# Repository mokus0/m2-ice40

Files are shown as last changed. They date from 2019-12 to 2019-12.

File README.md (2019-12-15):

This is a work in progress.  The end goal is to develop a m.2 3042 B-key (USB) board to install into my System76 Galago Pro laptop's internal 3G/LTE module socket, to provide a debugging and development tool for work on the system's Embedded Controller.

In particular, this board will include:
* a Lattice Semiconductor ICE40 FPGA with programming and USB interface (based on FTDI FT2232H high-speed USB interface as used in the "iCEstick" dev board, but upgraded from HX1K to HX4K FPGA)
* a MAX6621 I2C-to-PECI translator, to experiment with
* configurable power source; run from either 3.3v provided to the m.2 module or a wire to steal power from somewhere else in the system
* pads to connect FPGA as desired to various nets on the system board for monitoring and logging
* TODO (maybe in a second rev, and space permitting): a small microcontroller, perhaps STM32L4R5

Intended uses include:
* Investigating the traffic on the LPC bus, to develop sufficient understanding to be able to implement the bus in a new non-ITE processor, and later to monitor that processor's usage of the LPC bus for correctness
* Ability to log and monitor behavior of EC long-term

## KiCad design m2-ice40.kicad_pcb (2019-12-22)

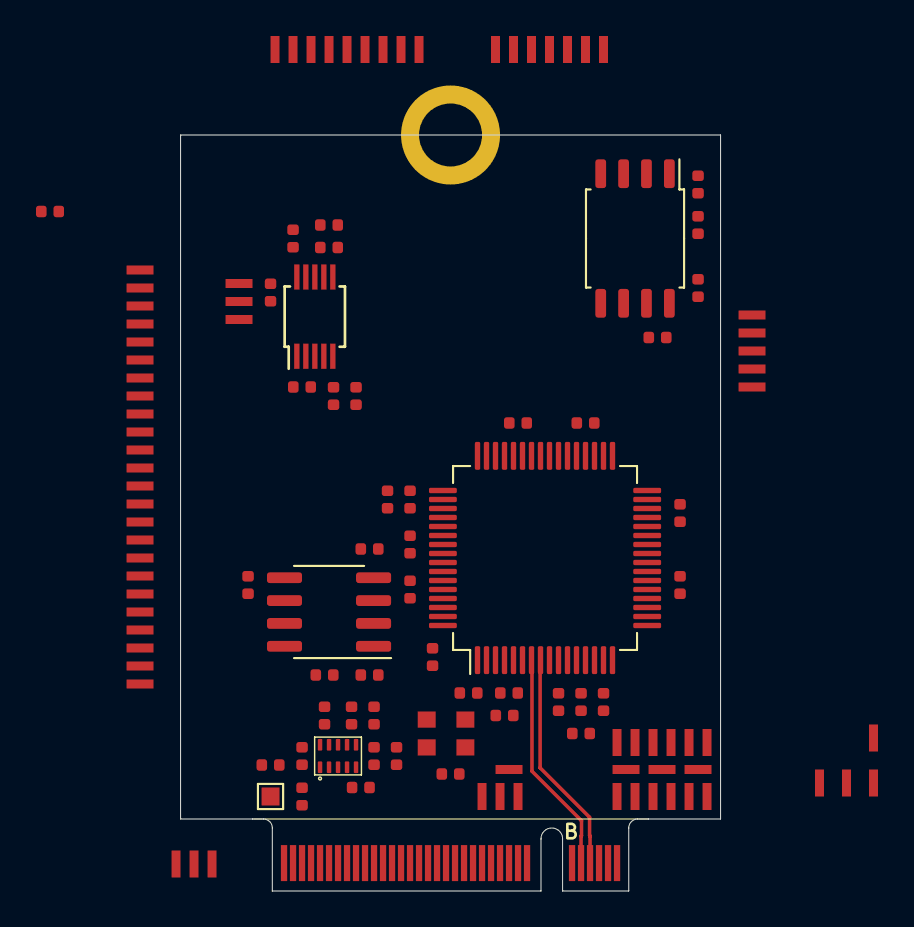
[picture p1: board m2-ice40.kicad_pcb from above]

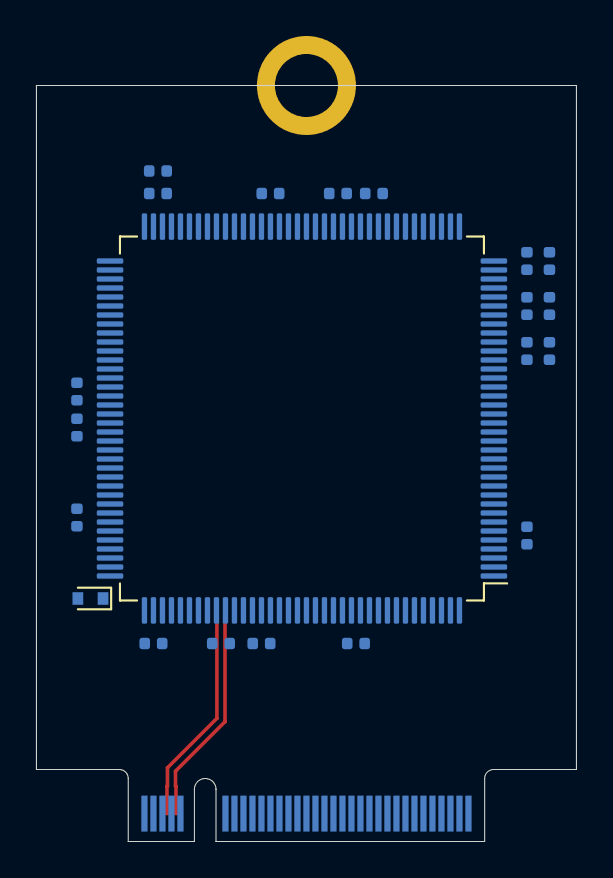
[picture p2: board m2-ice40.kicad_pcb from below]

Board: 4 copper layers, 30.0 x 42.0 mm, 146 parts (21 on the bottom side), 123 nets.

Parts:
C201, C202, C204, C207, C208, C209, C210, C211, C212, C213, C214, C215, C301, C302, C303, C304, C305, C306, C307, C308, C401, C402, C403, C406, C407, C408, C409, C701, C702: 0.1u; C_0402_1005Metric
C203, C404, C410, C503, C504: 10u; C_0402_1005Metric
C205, C206, C501: 4.7u; C_0402_1005Metric
C405: 0.01u; C_0402_1005Metric
C502: 120p; C_0402_1005Metric
D401: CDBU0520; D_SOD-523
J601: m.2_socket2_module; m2-padKeyB
J602: M.2-GND-MOUNTING; m.2_mechanical_ground_pad
R201, R203, R206, R401, R402, R403, R404, R701: 10k; R_0402_1005Metric
R202, R501, R502, R702: 0; R_0402_1005Metric
R204, R703, R704, R705: 2.2k; R_0402_1005Metric
R205: 12k 1%; R_0402_1005Metric
R207: 12k; R_0402_1005Metric
R405: 100; R_0402_1005Metric
R503, R504, R505: 100k; R_0402_1005Metric
TP101: PECI_VREF; TestPoint_Pad_0.5x1.5mm
TP102: PECI; TestPoint_Pad_0.5x1.5mm
TP103: PECI_GND; TestPoint_Pad_0.5x1.5mm
TP501: 3.3V_EXT; TestPoint_Pad_1.0x1.0mm
TP701, TP702, TP703, TP704, TP705, TP706, TP707, TP708, TP709, TP710, TP711, TP712, TP713, TP714, TP715, TP716, TP717, TP718, TP719, TP720, TP721, TP722, TP723, TP724, TP725, TP726, TP727, TP728, TP729, TP730, TP731, TP732, TP733, TP734, TP735, TP736, TP737, TP738, TP739, TP740, TP741, TP742, TP743, TP744, TP745, TP746, TP747, TP748, TP749, TP750, TP751, TP752, TP753, TP754, TP755, TP756, TP757, TP758, TP759, TP760, TP761, TP762, TP763, TP764, TP765, TP766, TP767, TP768, TP769, TP770, TP771: TestPoint; TestPoint_Pad_0.5x1.5mm
U201: 93LC56C-I/SN; SOIC-8_3.9x4.9mm_P1.27mm
U202: FT2232H; LQFP-64_10x10mm_P0.5mm
U301: ICE40HX1K-TQ144; TQFP-144_20x20mm_P0.5mm
U401: W25Q80DVSNIG; SOIC-8_5.23x5.23mm_P1.27mm
U501: TPSM82821; SIL0010D
U701: MAX6621; MSOP-10_3x3mm_P0.5mm
X201: DSC6001JI2A-012.0000; Oscillator_SMD_EuroQuartz_XO32-4Pin_3.2x2.5mm

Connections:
/FPGA/1.8v_OD_SIM_DETECT: J601.66, U301.139
/FPGA/ACBUS0: U202.26, U301.97
/FPGA/ACBUS1: U202.27, U301.96
/FPGA/ACBUS2: U202.28, U301.95
/FPGA/ACBUS3: U202.29, U301.91
/FPGA/ACBUS4: U202.30, U301.90
/FPGA/ACBUS5: U202.32, U301.88
/FPGA/ACBUS6: U202.33, U301.87
/FPGA/ACBUS7: U202.34, U301.81
/FPGA/ADBUS7: U202.24, U301.98
/FPGA/DISABLE#: J601.8, U301.121
/FPGA/FTDI_CTS: U202.19, U301.104
/FPGA/FTDI_DCD: U202.23, U301.99
/FPGA/FTDI_DSR: U202.22, U301.101
/FPGA/FTDI_DTR: U202.21, U301.102
/FPGA/FTDI_RTS: U202.18, U301.105
/FPGA/FTDI_RX__ICE_TX: U202.17, U301.106
/FPGA/FTDI_TX__ICE_RX: U202.16, U301.107
/FPGA/ICE_CLK: R202.1, U301.129
/FPGA/PECI_RESET#: R701.1, U301.39, U701.8
/FPGA/PECI_SCL: R705.2, U301.42, U701.5
/FPGA/PECI_SDA: R704.2, U301.41, U701.4
/FPGA/POWER_OFF#: J601.6, U301.120
/FPGA/RESET#: J601.67, U301.141
/FPGA/UIM_CLK: J601.32, U301.136
/FPGA/UIM_DATA: J601.34, U301.137
/FPGA/UIM_PWR: J601.36, U301.138
/FPGA/UIM_RESET: J601.30, U301.135
/fpga power and config/1.2V: C405.1, C406.1, C407.1, C408.1, C409.1, C410.1, C502.1, C503.1, C504.1, R405.1, R503.1, R504.1, U301.27, U301.51, U301.92, U301.111, U501.5, U501.6, U501.7
/fpga power and config/3.3V: C201.1, C202.1, C205.1, C206.1, C207.1, C208.1, C209.1, C211.1, C213.1, C215.1, C301.1, C302.1, C303.1, C304.1, C305.1, C306.1, C307.1, C308.1, C401.1, C402.1, C501.1, C701.1, D401.2, R201.1, R203.1, R206.1, R207.1, R401.1, R402.2, R403.2, R404.1, R501.1, R502.1, R701.2, R703.1, R704.1, R705.1, U201.6, U201.8, U202.4, U202.9, U202.20, U202.31, U202.42, U202.50, U202.56, U301.6, U301.30, U301.46, U301.57, U301.72, U301.89, U301.100, U301.123, U301.133, U401.8, U501.1, U501.2, U501.3, U701.6, X201.1, X201.4
/fpga power and config/CDONE: U202.45, U301.65
/fpga power and config/CRESET: R404.2, U202.46, U301.66
/fpga power and config/GNDPLL: C403.2, C404.2, U301.35
/fpga power and config/VCCPLL: C403.1, C404.1, R405.2, U301.36
/ftdi/FTDI_1.8V: C203.1, C204.1, C210.1, C212.1, C214.1, U202.12, U202.37, U202.49, U202.64
/ftdi/ICE_MISO: U202.40, U301.68, U401.2
/ftdi/ICE_MOSI: U202.39, U301.67, U401.5
/ftdi/ICE_SCK: U202.38, U301.70, U401.6
/ftdi/ICE_SS_B: R401.2, U202.43, U301.71, U401.1
/ftdi/USB_D+: J601.7, U202.8
/ftdi/USB_D-: J601.9, U202.7
/m2-conn/3.3V: J601.2, J601.4, J601.70, J601.72, J601.74, R501.2
/peci/ALERT#: R703.2, U301.38, U701.9
/peci/PECI: TP102.1, U701.1
/peci/PECI_GND: C702.2, R702.1, TP103.1, U701.2
/peci/PECI_VREF: C702.1, TP101.1, U701.10
GND: C201.2, C202.2, C203.2, C204.2, C205.2, C206.2, C207.2, C208.2, C209.2, C210.2, C211.2, C212.2, C213.2, C214.2, C215.2, C301.2, C302.2, C303.2, C304.2, C305.2, C306.2, C307.2, C308.2, C401.2, C402.2, C405.2, C406.2, C407.2, C408.2, C409.2, C410.2, C501.2, C503.2, C504.2, C701.2, J601.3, J601.5, J601.11, J601.21, J601.27, J601.33, J601.39, J601.45, J601.51, J601.57, J601.71, J601.73, J602.1, R205.1, R505.2, R702.2, TP764.1, TP765.1, TP766.1, TP767.1, TP768.1, TP769.1, TP770.1, TP771.1, U201.5, U202.1, U202.5, U202.10, U202.11, U202.13, U202.15, U202.25, U202.35, U202.47, U202.51, U301.5, U301.13, U301.14, U301.59, U301.69, U301.86, U301.103, U301.132, U301.140, U401.4, U501.9, U501.10, U701.3, U701.7, X201.2
unnamed: C502.2, R504.2, R505.1, U501.8
unnamed: D401.1, U301.108
unnamed: R201.2, R204.2, U201.4
unnamed: R202.2, U202.2, X201.3
unnamed: R203.2, U201.2, U202.62
unnamed: R204.1, U201.3, U202.61
unnamed: R205.2, U202.6
unnamed: R206.2, U201.1, U202.63
unnamed: R207.2, U202.14
unnamed: R402.1, U401.7
unnamed: R403.1, U401.3
unnamed: R502.2, TP501.1
unnamed: R503.2, U501.4
unnamed: TP701.1, U301.112
unnamed: TP702.1, U301.113
unnamed: TP703.1, U301.114
unnamed: TP704.1, U301.115
unnamed: TP705.1, U301.116
unnamed: TP706.1, U301.117
unnamed: TP707.1, U301.118
unnamed: TP708.1, U301.119
unnamed: TP709.1, U301.122
unnamed: TP710.1, U301.128
unnamed: TP711.1, U301.134
unnamed: TP712.1, U301.142
unnamed: TP713.1, U301.143
unnamed: TP714.1, U301.144
unnamed: TP715.1, U301.73
unnamed: TP716.1, U301.74
unnamed: TP717.1, U301.75
unnamed: TP718.1, U301.76
unnamed: TP719.1, U301.78
unnamed: TP720.1, U301.79
unnamed: TP721.1, U301.80
unnamed: TP722.1, U301.93
unnamed: TP723.1, U301.94
unnamed: TP724.1, U301.37
unnamed: TP725.1, U301.43
unnamed: TP726.1, U301.44
unnamed: TP727.1, U301.45
unnamed: TP728.1, U301.47
unnamed: TP729.1, U301.48
unnamed: TP730.1, U301.49
unnamed: TP731.1, U301.50
unnamed: TP732.1, U301.52
unnamed: TP733.1, U301.56
unnamed: TP734.1, U301.58
unnamed: TP735.1, U301.60
unnamed: TP736.1, U301.61
unnamed: TP737.1, U301.62
unnamed: TP738.1, U301.63
unnamed: TP739.1, U301.64
unnamed: TP740.1, U301.1
unnamed: TP741.1, U301.2
unnamed: TP742.1, U301.3
unnamed: TP743.1, U301.4
unnamed: TP744.1, U301.7
unnamed: TP745.1, U301.8
unnamed: TP746.1, U301.9
unnamed: TP747.1, U301.10
unnamed: TP748.1, U301.11
unnamed: TP749.1, U301.12
unnamed: TP750.1, U301.19
unnamed: TP751.1, U301.20
unnamed: TP752.1, U301.21
unnamed: TP753.1, U301.22
unnamed: TP754.1, U301.23
unnamed: TP755.1, U301.24
unnamed: TP756.1, U301.25
unnamed: TP757.1, U301.26
unnamed: TP758.1, U301.28
unnamed: TP759.1, U301.29
unnamed: TP760.1, U301.31
unnamed: TP761.1, U301.32
unnamed: TP762.1, U301.33
unnamed: TP763.1, U301.34

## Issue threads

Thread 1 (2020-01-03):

clarification project

th1j5, 2020-01-03:
Hey @mokus0 ,

I'm a student electrotechnical engineer and since having a galp3(-b), I became interested in your project.
If I understand it correct, you want to replace the Embedded Controller instead of reverse engineering firmware for the chip already in the laptop (like system76 is doing)?

This semester (I'm in my 3th year out of 5) were doing a project and we can submit our own proposals (before 10 january).
I thought about proposing this as a project, but in order to do so, it will probably have to be more general... (I'm not willing to donate my laptop as a testsubject :)

This measurement board you're making to monitor the traffic on the Low Pin Count bus, do you know how generaly applicable it would be? I don't know yet which differences there would be between various laptops (despite al having an EC according to my knowledge...?)
If you have some pointers about these issues...

Since being a student, I'm not yet accustomed with all the abbreviations you use (but I have ecosia ~ like google) nor with everything I saw in Kicad, but I can only learn.
1 question dumped in the middle:
  I guess the m2-conn module is the module that gets connected to the LPC, but to understand how this turns out, I probably have to look at the LPC bus in the hardware plans of the galp?

Furthermore, I want to stress that it's only an idea and that I already submitted 2 other proposals (I'm busy), so it's not very probably that this would become a project.

If this does not become a project, I won't spend time in this (to be clear), but I have to say again that it looks nice and I surely will watch this either way.

th1j5, 2020-01-08:
I did submit this as an idea (<> proposal) at my university course.
I included the idea (pdf) for convenience, since concerning your project.
It is however in Dutch
[projectidee_ec.pdf](https://github.com/mokus0/m2-ice40/files/4037340/projectidee_ec.pdf)

Greetings

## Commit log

2019-12-15 rough draft of first design
    [fpga-power-and-config.sch, fpga.sch, ftdi.sch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]
2019-12-15 initial footprint assignment and VERY rough placement
    [fpga-power-and-config.sch, fpga.sch, ftdi.sch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]
2019-12-16 added a couple more footprints
    [m2-conn.sch, m2-ice40.kicad_pcb, power.sch]
2019-12-21 local component placement
    [fpga-power-and-config.sch, ftdi.sch, m2-ice40.kicad_pcb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]
2019-12-22 assigning pins, adding test points, placing stuff, etc
    [fpga-power-and-config.sch, fpga.sch, ftdi.sch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]
